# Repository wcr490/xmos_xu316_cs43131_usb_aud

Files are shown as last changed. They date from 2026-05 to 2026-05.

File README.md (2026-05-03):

# xmos_xu316_cs43131_usb_aud

## Firmware Compilation Steps

* install xmos xtc tools vscode extension
* clone (https://github.com/youheng7185/sw_usb_audio.git)
* open with vscode, try building
* after getting error from lib_board_support, delete the lib_board_support and clone this (https://github.com/youheng7185/lib_board_support) into that directory
* when build finishes, run ```./pack.sh``` to generate the rom for qspi flash
* flash qspi flash with ```output.bin```

## Reference

* Bric for its cs43131 schematics and init sequence (https://github.com/zephray/Bric)
* Blog by WuXi for cs43131 registers (https://wuxiproj.mzy7.cn/posts/a75c0c32)

## Main Component
* XU316-1024-QF60B-C24
* STMicro USB6B1 USB ESD protection
* Generic USB-C 2.0 TH port
* Winbond W25Q64JVS
* Seiko Epson FA-238 (24 Mhz)
* TI TPS563201 (1.8v dcdc), this requires a 252012 size 2.2uH inductor
* RT9013-33GB, 3.3v ldo
* RT9013-18GB, 1.8v ldo (x4, notes: inside the schematics, 1.8v ldo also uses 3.3v ldo symbol)
* NDK NZ2520SDA-24.576MHZ
* Cirrus Logic CS43131-CNZR
* PJ-327A0-SMT (audio jack)
* TI PCA9306DCUR
* TI SN74AVC4T774PWR
* common values of resistor and capacitor

## Pictures

audio_settings


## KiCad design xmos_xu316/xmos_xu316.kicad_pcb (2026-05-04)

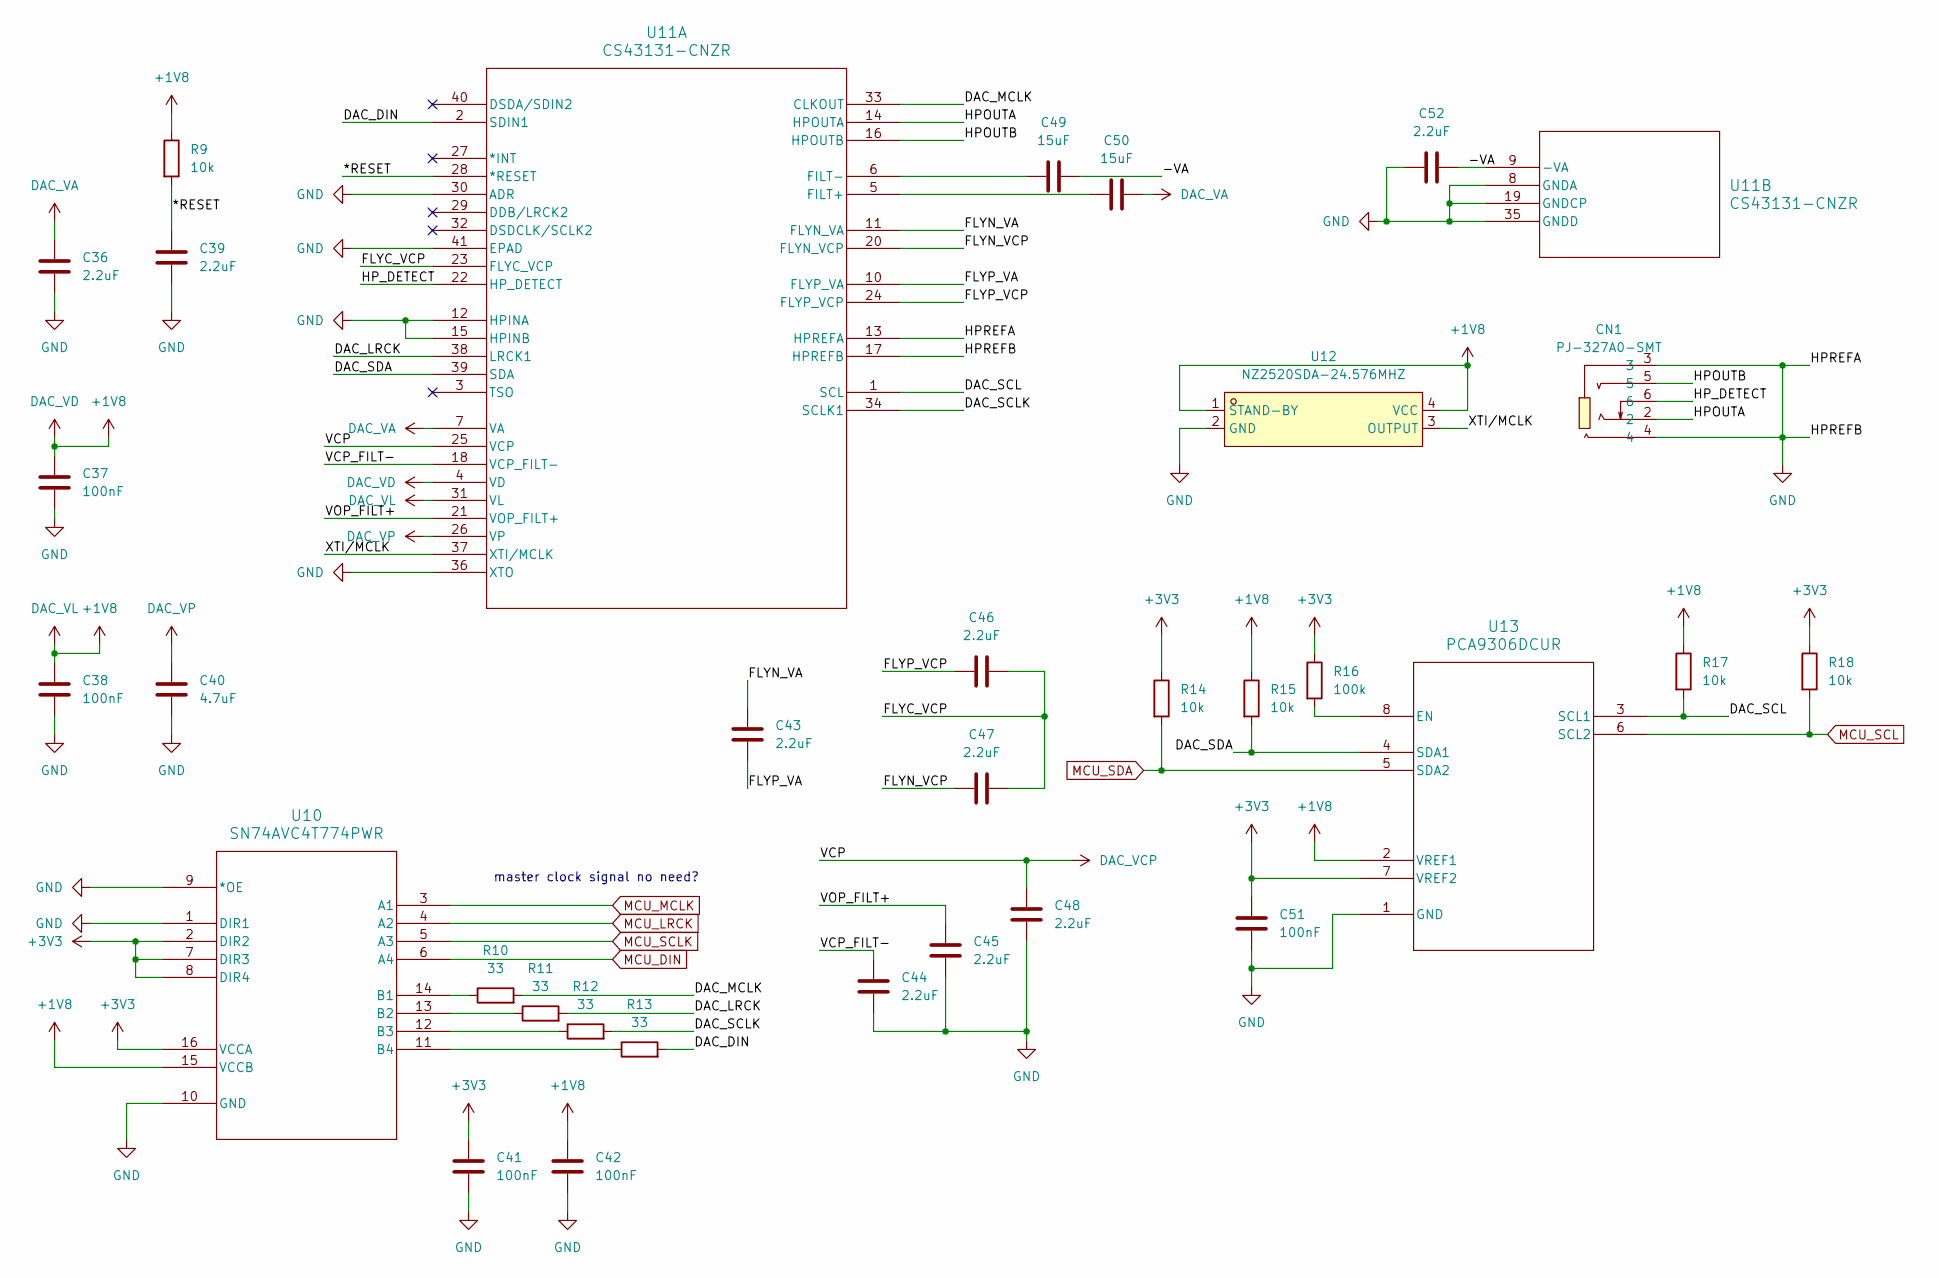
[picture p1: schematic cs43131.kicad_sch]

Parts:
C36, C39, C43, C44, C45, C46, C47, C48, C52: 2.2uF; C_0603_1608Metric
C37, C38, C41, C42, C51: 100nF; C_0603_1608Metric
C40: 4.7uF; C_0603_1608Metric
C49, C50: 15uF; C_0603_1608Metric
CN1: PJ-327A0-SMT; AUDIO-SMD_PJ-327A0-SMT; LCSC Part C381135
R9, R14, R15, R17, R18: 10k; R_0603_1608Metric
R10, R11, R12, R13: 33; R_0603_1608Metric
R16: 100k; R_0603_1608Metric
U10: SN74AVC4T774PWR; PW16-M
U11: CS43131-CNZR; QFN40_CS43131-CNZR_CIR-M
U12: NZ2520SDA-24.576MHZ; OSC-SMD_4P-L2.5-W2.0-BL_YSO8008MR; LCSC Part C2846938
U13: PCA9306DCUR; DCU8-M

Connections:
+1V8: C37.1, C38.1, C42.1, R9.1, R15.1, R17.1, U10.15 (VCCB), U11.4 (VD), U11.31 (VL), U12.1 (STAND-BY), U12.4 (VCC), U13.2 (VREF1); also elsewhere on the board
+3V3: C41.1, C51.1, R14.1, R16.1, R18.1, U10.2 (DIR2), U10.7 (DIR3), U10.8 (DIR4), U10.16 (VCCA), U13.7 (VREF2); also elsewhere on the board
/cs43131/*RESET: C39.1, R9.2, U11.28 (*RESET)
/cs43131/-VA: C49.2, C52.2, U11.9 (-VA)
/cs43131/DAC_DIN: R13.2, U11.2 (SDIN1)
/cs43131/DAC_LRCK: R11.2, U11.38 (LRCK1)
/cs43131/DAC_MCLK: R10.2, U11.33 (CLKOUT)
/cs43131/DAC_SCL: R17.2, U11.1 (SCL), U13.3 (SCL1)
/cs43131/DAC_SCLK: R12.2, U11.34 (SCLK1)
/cs43131/DAC_SDA: R15.2, U11.39 (SDA), U13.4 (SDA1)
/cs43131/FLYC_VCP: C46.2, C47.2, U11.23 (FLYC_VCP)
/cs43131/FLYN_VA: C43.1, U11.11 (FLYN_VA)
/cs43131/FLYN_VCP: C47.1, U11.20 (FLYN_VCP)
/cs43131/FLYP_VA: C43.2, U11.10 (FLYP_VA)
/cs43131/FLYP_VCP: C46.1, U11.24 (FLYP_VCP)
/cs43131/HPOUTA: CN1.2, U11.14 (HPOUTA)
/cs43131/HPOUTB: CN1.5, U11.16 (HPOUTB)
/cs43131/HP_DETECT: CN1.6, U11.22 (HP_DETECT)
/cs43131/VCP_FILT-: C44.1, U11.18 (VCP_FILT-)
/cs43131/VOP_FILT+: C45.1, U11.21 (VOP_FILT+)
/cs43131/XTI/MCLK: U11.37 (XTI/MCLK), U12.3 (OUTPUT)
DAC_VA: C36.1, C50.2, U11.7 (VA); also elsewhere on the board
DAC_VCP: C48.1, U11.25 (VCP); also elsewhere on the board
DAC_VP: C40.1, U11.26 (VP); also elsewhere on the board
GND: C36.2, C37.2, C38.2, C39.2, C40.2, C41.2, C42.2, C44.2, C45.2, C48.2, C51.2, C52.1, CN1.3, CN1.4, U10.1 (DIR1), U10.9 (*OE), U10.10 (GND), U11.8 (GNDA), U11.12 (HPINA), U11.13 (HPREFA), U11.15 (HPINB), U11.17 (HPREFB), U11.19 (GNDCP), U11.30 (ADR), U11.35 (GNDD), U11.36 (XTO), U11.41 (EPAD), U12.2 (GND), U13.1 (GND); also elsewhere on the board
MCU_DIN: U10.6 (A4); also elsewhere on the board
MCU_LRCK: U10.4 (A2); also elsewhere on the board
MCU_MCLK: U10.3 (A1); also elsewhere on the board
MCU_SCL: R18.2, U13.6 (SCL2); also elsewhere on the board
MCU_SCLK: U10.5 (A3); also elsewhere on the board
MCU_SDA: R14.2, U13.5 (SDA2); also elsewhere on the board
unnamed: R10.1, U10.14 (B1)
unnamed: R11.1, U10.13 (B2)
unnamed: R12.1, U10.12 (B3)
unnamed: R13.1, U10.11 (B4)
unnamed: C50.1, U11.5 (FILT+)
unnamed: C49.1, U11.6 (FILT-)
unnamed: R16.2, U13.8 (EN)

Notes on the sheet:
master clock signal no need?

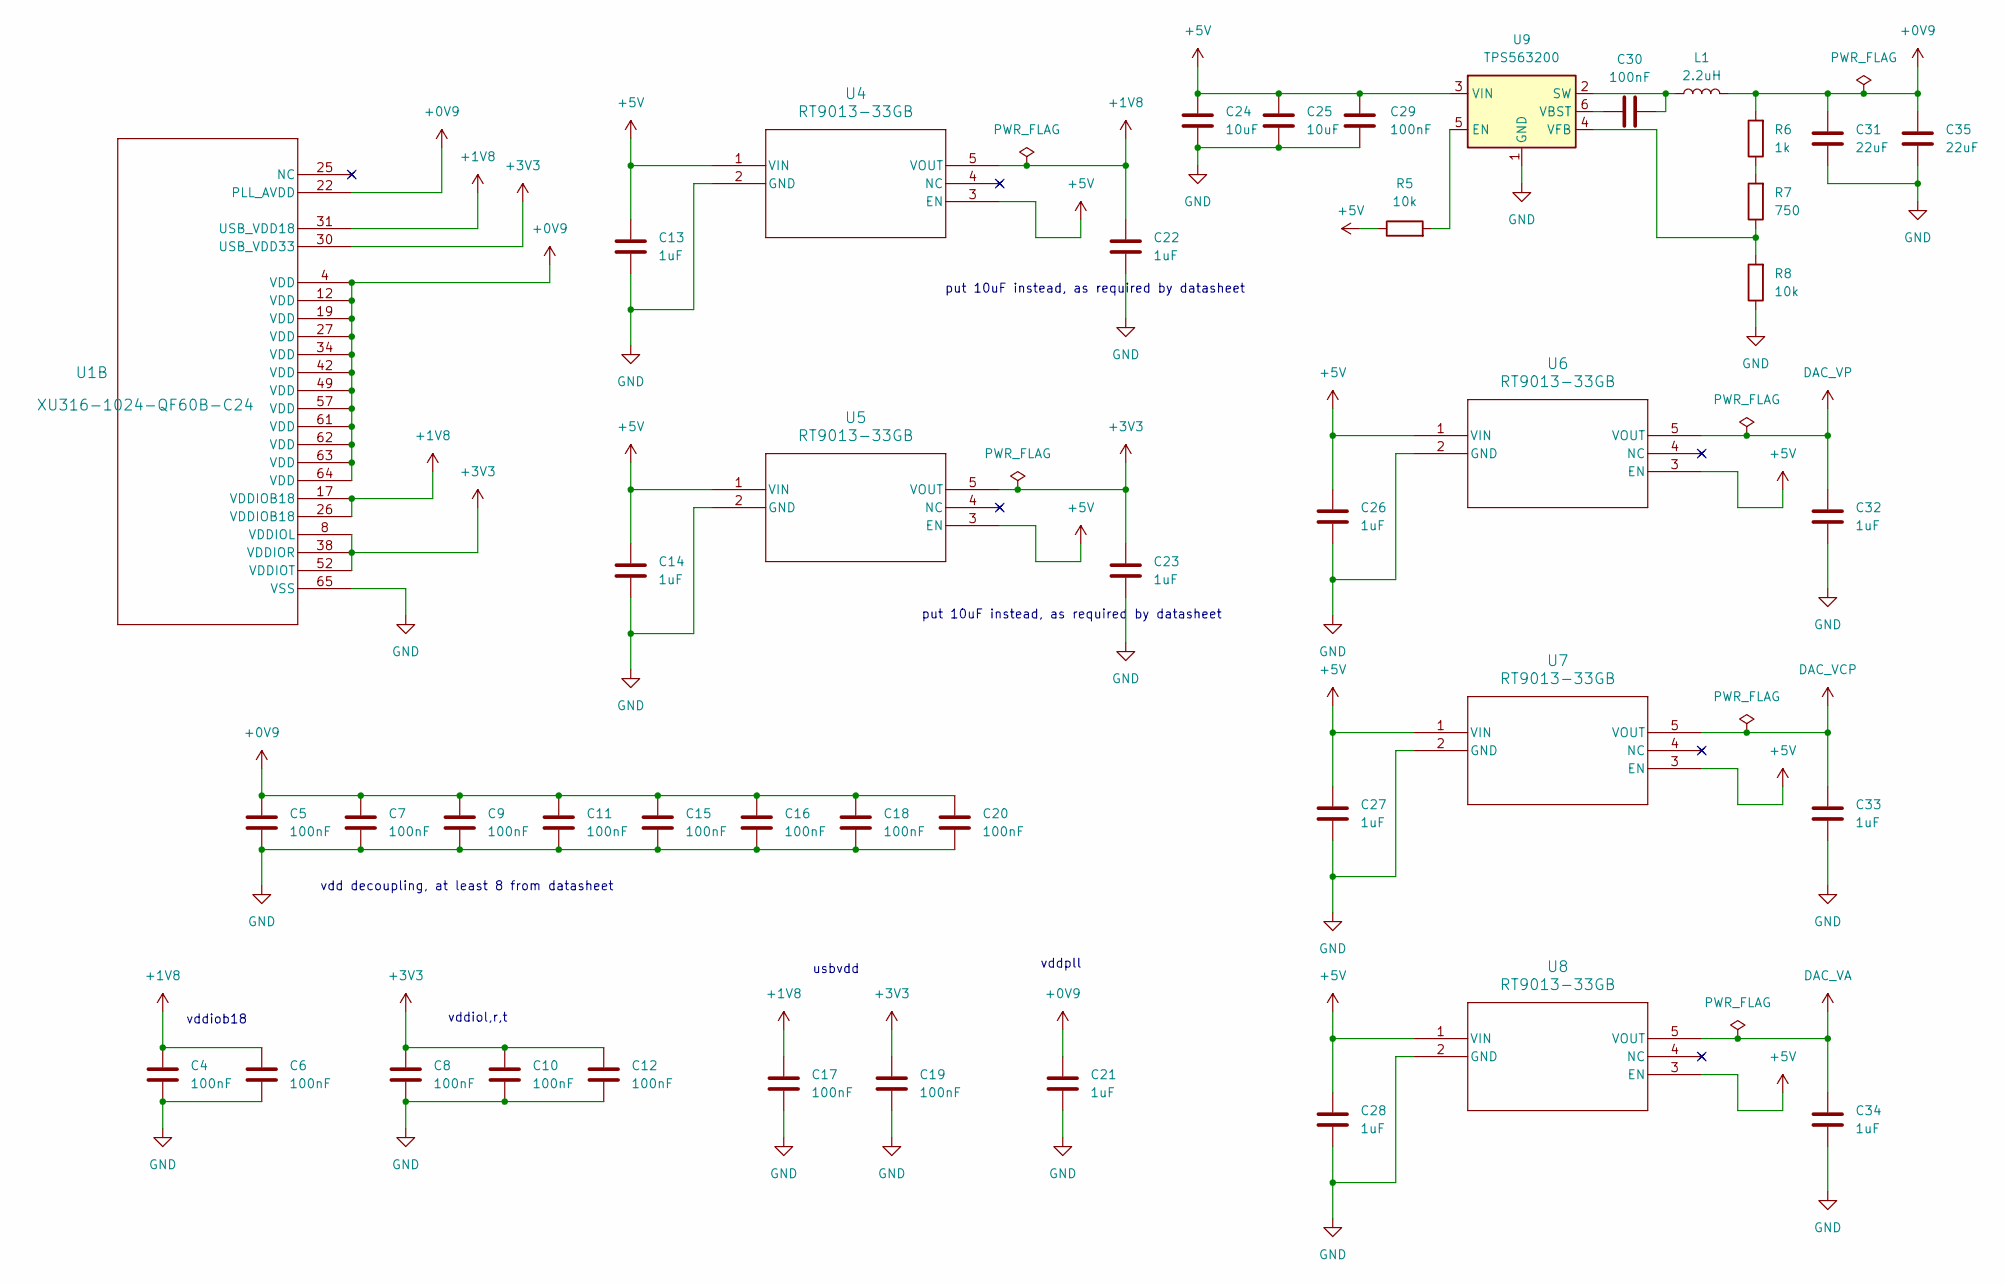
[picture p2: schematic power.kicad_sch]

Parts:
C4, C5, C6, C7, C8, C9, C10, C11, C12, C15, C16, C17, C18, C19, C20, C29, C30: 100nF; C_0603_1608Metric
C13, C14, C21, C22, C23, C26, C27, C28, C32, C33, C34: 1uF; C_0603_1608Metric
C24, C25: 10uF; C_0603_1608Metric
C31, C35: 22uF; C_0603_1608Metric
L1: 2.2uH; L_Sunlord_SWPA252012S
R5, R8: 10k; R_0603_1608Metric
R6: 1k; R_0603_1608Metric
R7: 750; R_0603_1608Metric
U1: XU316-1024-QF60B-C24; QFN_F60B-C24_XMO
U4, U5, U6, U7, U8: RT9013-33GB; SOT-23-5_RT9013
U9: TPS563200; SOT-23-6

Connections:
+0V9: C5.1, C7.1, C9.1, C11.1, C15.1, C16.1, C18.1, C20.1, C21.1, C31.1, C35.1, L1.2, R6.2, U1.4 (VDD), U1.12 (VDD), U1.19 (VDD), U1.22 (PLL_AVDD), U1.27 (VDD), U1.34 (VDD), U1.42 (VDD), U1.49 (VDD), U1.57 (VDD), U1.61 (VDD), U1.62 (VDD), U1.63 (VDD), U1.64 (VDD)
+1V8: C4.1, C6.1, C17.1, C22.1, U1.17 (VDDIOB18), U1.26 (VDDIOB18), U1.31 (USB_VDD18), U4.5 (VOUT); also elsewhere on the board
+3V3: C8.1, C10.1, C12.1, C19.1, C23.1, U1.8 (VDDIOL), U1.30 (USB_VDD33), U1.38 (VDDIOR), U1.52 (VDDIOT), U5.5 (VOUT); also elsewhere on the board
+5V: C13.1, C14.1, C24.1, C25.1, C26.1, C27.1, C28.1, C29.2, R5.1, U4.1 (VIN), U4.3 (EN), U5.1 (VIN), U5.3 (EN), U6.1 (VIN), U6.3 (EN), U7.1 (VIN), U7.3 (EN), U8.1 (VIN), U8.3 (EN), U9.3 (VIN); also elsewhere on the board
DAC_VA: C34.1, U8.5 (VOUT); also elsewhere on the board
DAC_VCP: C33.1, U7.5 (VOUT); also elsewhere on the board
DAC_VP: C32.1, U6.5 (VOUT); also elsewhere on the board
GND: C4.2, C5.2, C6.2, C7.2, C8.2, C9.2, C10.2, C11.2, C12.2, C13.2, C14.2, C15.2, C16.2, C17.2, C18.2, C19.2, C20.2, C21.2, C22.2, C23.2, C24.2, C25.2, C26.2, C27.2, C28.2, C29.1, C31.2, C32.2, C33.2, C34.2, C35.2, R8.1, U1.65 (VSS), U4.2 (GND), U5.2 (GND), U6.2 (GND), U7.2 (GND), U8.2 (GND), U9.1 (GND); also elsewhere on the board
unnamed: R6.1, R7.2
unnamed: R5.2, U9.5 (EN)
unnamed: C30.2, L1.1, U9.2 (SW)
unnamed: C30.1, U9.6 (VBST)
unnamed: R7.1, R8.2, U9.4 (VFB)

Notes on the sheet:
vdd decoupling, at least 8 from datasheet
put 10uF instead, as required by datasheet
vddiol,r,t
vddiob18
vddpll
usbvdd

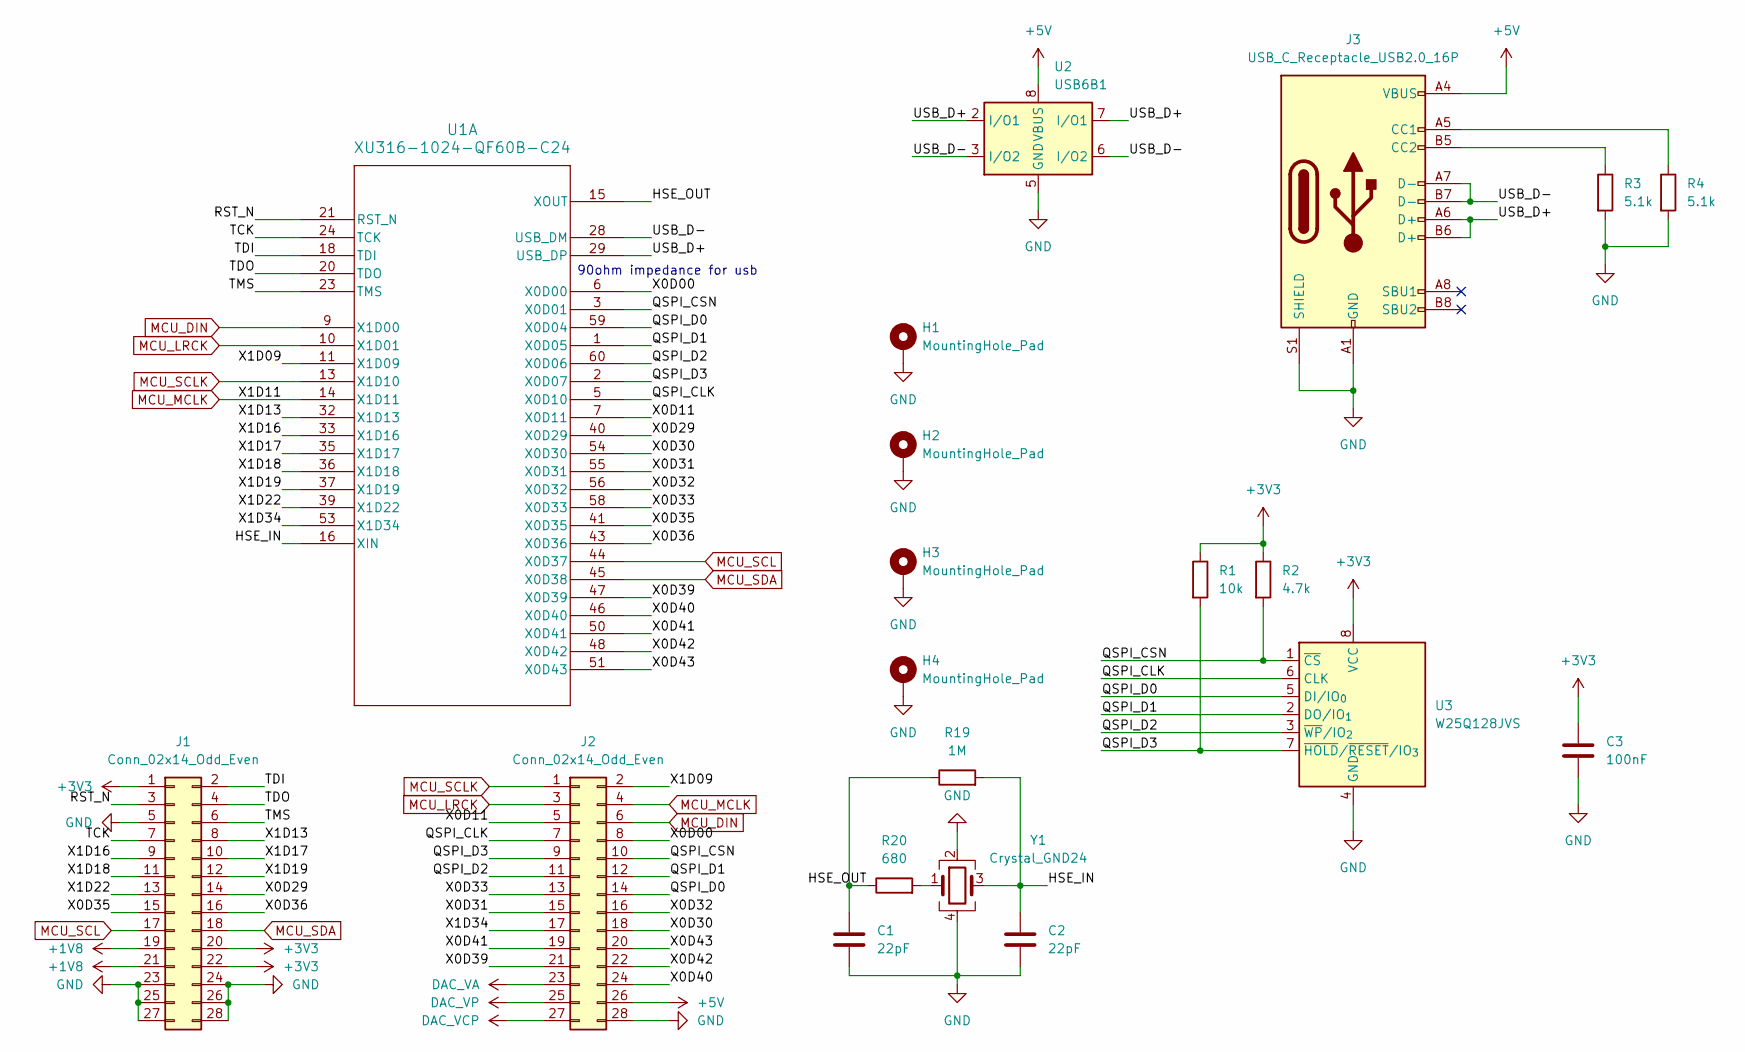
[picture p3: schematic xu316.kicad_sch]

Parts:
C1, C2: 22pF; C_0603_1608Metric
C3: 100nF; C_0603_1608Metric
H1, H2, H3, H4: MountingHole_Pad; MountingHole_2.7mm_M2.5_DIN965_Pad_TopBottom
J1, J2: Conn_02x14_Odd_Even; PinHeader_2x14_P2.54mm_Vertical
J3: USB_C_Receptacle_USB2.0_16P; USB_C_Receptacle_GCT_USB4105-xx-A_16P_TopMnt_Horizontal
R1: 10k; R_0603_1608Metric
R2: 4.7k; R_0603_1608Metric
R3, R4: 5.1k; R_0603_1608Metric
R19: 1M; R_0603_1608Metric
R20: 680; R_0603_1608Metric
U1: XU316-1024-QF60B-C24; QFN_F60B-C24_XMO
U2: USB6B1; SOIC-8_3.9x4.9mm_P1.27mm
U3: W25Q128JVS; SOIC-8_5.3x5.3mm_P1.27mm
Y1: Crystal_GND24; Crystal_SMD_3225-4Pin_3.2x2.5mm

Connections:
+1V8: J1.19, J1.21; also elsewhere on the board
+3V3: C3.1, J1.1, J1.20, J1.22, R1.1, R2.1, U3.8 (VCC); also elsewhere on the board
+5V: J2.26, J3.A4 (VBUS), J3.A9 (VBUS), J3.B4 (VBUS), J3.B9 (VBUS), U2.1 (VBUS), U2.8 (VBUS); also elsewhere on the board
/xu316/HSE_IN: C2.1, R19.2, U1.16 (XIN), Y1.3
/xu316/HSE_OUT: C1.1, R19.1, R20.1, U1.15 (XOUT)
/xu316/QSPI_CLK: J2.7, U1.5 (X0D10), U3.6 (CLK)
/xu316/QSPI_CSN: J2.10, R2.2, U1.3 (X0D01), U3.1 (~CS)
/xu316/QSPI_D0: J2.14, U1.59 (X0D04), U3.5 (DI/IO_{0})
/xu316/QSPI_D1: J2.12, U1.1 (X0D05), U3.2 (DO/IO_{1})
/xu316/QSPI_D2: J2.11, U1.60 (X0D06), U3.3 (~WP/IO_{2})
/xu316/QSPI_D3: J2.9, R1.2, U1.2 (X0D07), U3.7 (~HOLD/~RESET/IO_{3})
/xu316/RST_N: J1.3, U1.21 (RST_N)
/xu316/TCK: J1.7, U1.24 (TCK)
/xu316/TDI: J1.2, U1.18 (TDI)
/xu316/TDO: J1.4, U1.20 (TDO)
/xu316/TMS: J1.6, U1.23 (TMS)
/xu316/USB_D+: J3.A6 (D+), J3.B6 (D+), U1.29 (USB_DP), U2.2 (I/O1), U2.7 (I/O1)
/xu316/USB_D-: J3.A7 (D-), J3.B7 (D-), U1.28 (USB_DM), U2.3 (I/O2), U2.6 (I/O2)
/xu316/X0D00: J2.8, U1.6 (X0D00)
/xu316/X0D11: J2.5, U1.7 (X0D11)
/xu316/X0D29: J1.14, U1.40 (X0D29)
/xu316/X0D30: J2.18, U1.54 (X0D30)
/xu316/X0D31: J2.15, U1.55 (X0D31)
/xu316/X0D32: J2.16, U1.56 (X0D32)
/xu316/X0D33: J2.13, U1.58 (X0D33)
/xu316/X0D35: J1.15, U1.41 (X0D35)
/xu316/X0D36: J1.16, U1.43 (X0D36)
/xu316/X0D39: J2.21, U1.47 (X0D39)
/xu316/X0D40: J2.24, U1.46 (X0D40)
/xu316/X0D41: J2.19, U1.50 (X0D41)
/xu316/X0D42: J2.22, U1.48 (X0D42)
/xu316/X0D43: J2.20, U1.51 (X0D43)
/xu316/X1D09: J2.2, U1.11 (X1D09)
/xu316/X1D13: J1.8, U1.32 (X1D13)
/xu316/X1D16: J1.9, U1.33 (X1D16)
/xu316/X1D17: J1.10, U1.35 (X1D17)
/xu316/X1D18: J1.11, U1.36 (X1D18)
/xu316/X1D19: J1.12, U1.37 (X1D19)
/xu316/X1D22: J1.13, U1.39 (X1D22)
/xu316/X1D34: J2.17, U1.53 (X1D34)
DAC_VA: J2.23; also elsewhere on the board
DAC_VCP: J2.27; also elsewhere on the board
DAC_VP: J2.25; also elsewhere on the board
GND: C1.2, C2.2, C3.2, H1.1, H2.1, H3.1, H4.1, J1.5, J1.23, J1.24, J1.25, J1.26, J1.27, J1.28, J2.28, J3.A1 (GND), J3.A12 (GND), J3.B1 (GND), J3.B12 (GND), J3.S1 (SHIELD), R3.2, R4.2, U2.4 (GND), U2.5 (GND), U3.4 (GND), Y1.2, Y1.4; also elsewhere on the board
MCU_DIN: J2.6, U1.9 (X1D00); also elsewhere on the board
MCU_LRCK: J2.3, U1.10 (X1D01); also elsewhere on the board
MCU_MCLK: J2.4, U1.14 (X1D11); also elsewhere on the board
MCU_SCL: J1.17, U1.44 (X0D37); also elsewhere on the board
MCU_SCLK: J2.1, U1.13 (X1D10); also elsewhere on the board
MCU_SDA: J1.18, U1.45 (X0D38); also elsewhere on the board
unnamed: J3.A5 (CC1), R4.1
unnamed: J3.B5 (CC2), R3.1
unnamed: R20.2, Y1.1

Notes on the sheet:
90ohm impedance for usb

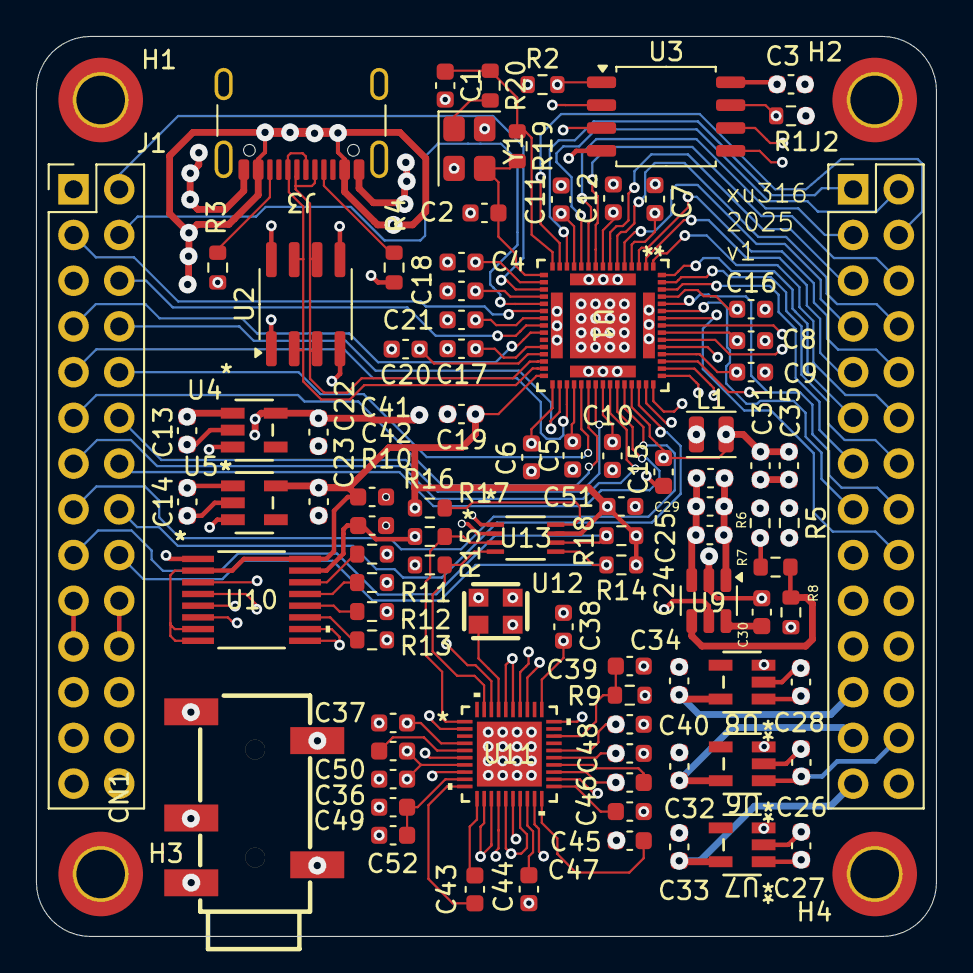
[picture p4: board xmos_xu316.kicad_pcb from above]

Board: 6 copper layers, 50.0 x 50.0 mm, 95 parts (0 on the bottom side), 85 nets.

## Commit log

2026-04-08 Update README with warnings and compilation steps
    Added warnings and detailed PCB errors and firmware compilation steps.
2026-04-08 add kicad proj
    [cs43131.kicad_sch, power.kicad_sch, xmos_xu316.kicad_pcb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]
2026-05-03 fixed pcb errors
    [cs43131.kicad_sch, power.kicad_sch, xmos_xu316.kicad_pcb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]
2026-05-04 fixed one more error(SN74AVC4T774)
    [xmos_xu316.kicad_pcb]
2026-05-04 add rd for HSE
    [xmos_xu316.kicad_pcb, xu316.kicad_sch]
